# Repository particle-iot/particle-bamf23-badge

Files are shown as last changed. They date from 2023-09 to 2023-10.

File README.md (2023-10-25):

# Particle Bay Area Maker Faire 2023 Water Balloon Badge 

## Our interactive game

If you stopped by the Particle booth for the 2023 Bay Area Maker Faire, spun the prize wheel, and were lucky enough to win our badge, we hope you had a blast playing! 

So, how does it work? Participants turn on their badge(s) and wait for the small LED to glow cyan, letting them know it's ready for a game match to begin. The badge has four buttons, each serving as a launcher for virtual water balloons. Each button triggers attacks with varying strengths, all determined by a virtual die roll. Players take turns launching virtual water balloons, and after an attack and counter-attack, the badges will display the result of the match automatically.  The badge lights up green for a win, red for loss, or blue for a draw.  Players engage with fellow attendees in virtual water balloon battles, roll the dice, aim for high-strength attacks, and secure their win!

Players can only battle the same player up to 10 times (after which badges win glow white to alert you of the limit), so everyone must engage with new players to climb up the leaderboard.

Pro Tip: Point the die side edges of the badges towards each other for the best results (like the video below). The max distance is 10 feet, but the closer you are, the better.

Fun fact: iPhone IR depth mapping is detrimental to gameplay functionality.  So if you are wondering why your badges seem camera shy while videoing, this is why :D

## Gameplay

badge
cyberdeck

## Behind the Badge

The Photon 2 based badge isn't just a fun toy. With features like a dual-row socket for Photon 2, an ON/OFF switch, lanyard slots, 7 neopixel RGB LEDs, humidity and temperature sensor, QWIIC/Stemma connector, and a speaker, it's also a toolkit for your post-conference projects. The badge's 38kHz IR demodulator and LEDs also ensure efficient communication for the game.

## Hardware

All the parts are described in Bill of Materials [particle-bamf23-badge.csv](hardware/v1.0/pcb/)

OSHPark is a good place to order with purple or the new "after dark" theme color scheme.  You can upload the KiCad [particle-bamf23-badge.kicad_pcb](hardware/v1.0/pcb/) there directly.  I would download this entire Github repo ZIP file first though instead of just trying to save the PCB file from your browser.

Another way to order PCB's is by using the included [gerbers](hardware/v1.0/gerbers/) and uploading those with all of the necessary specs to companies like [PCBWay](https://www.pcbway.com) or [JLCPCB](https://jlcpcb.com)

The cyberdeck is a Raspberry Pi 400 computer, with Pimoroni Hyperpixel 4.0 Square LCD, along with another water balloon badge for input.  The badge is powered and connected to the pi over USB, and takes input on USB serial /dev/ttyACM0.  Everything was mounted to a laser cut acrylic piece that was bent at a nice angle.  The 40-pin cable was a real pain to make, since every pair of wires was twisted to ensure the proper orientation.  I highly suggest buying one of Adafruit's cyberdeck boards instead.

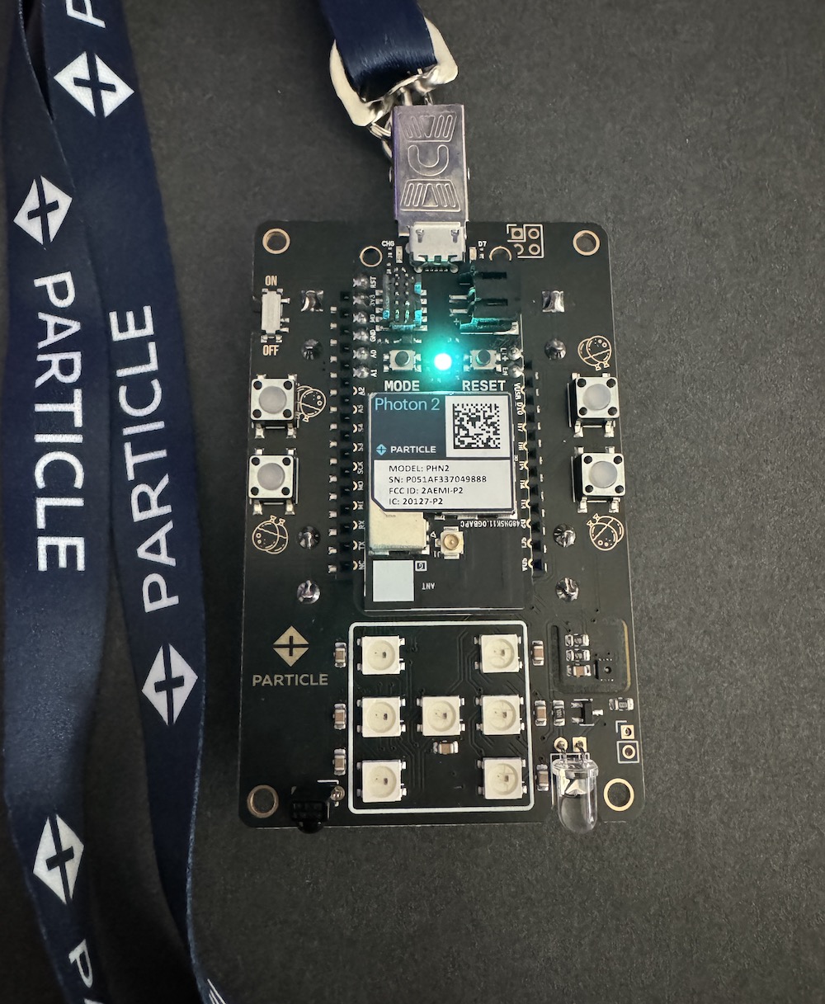
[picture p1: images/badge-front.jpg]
badge front

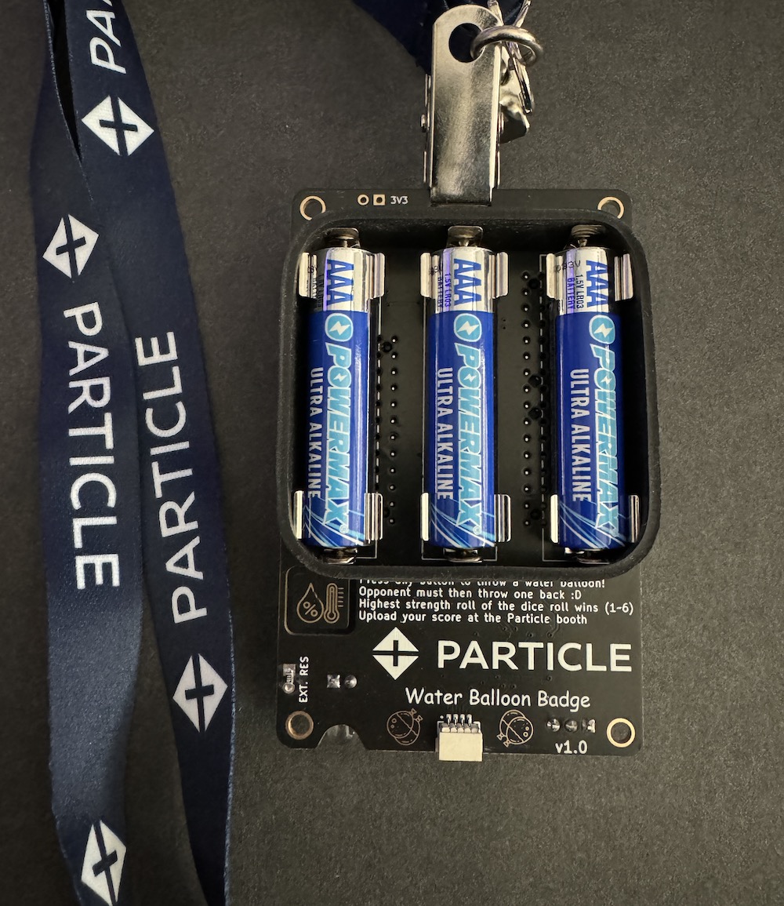
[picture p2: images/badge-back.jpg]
badge back

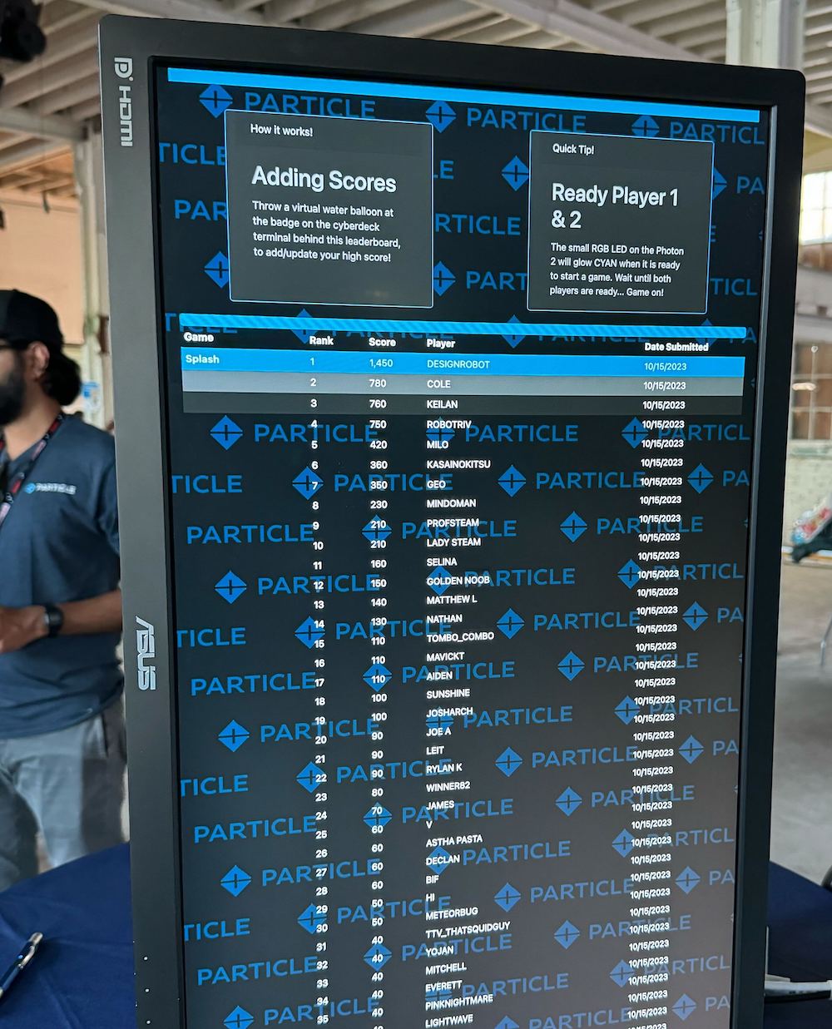
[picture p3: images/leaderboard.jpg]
badge


## Software

```
software/v1.0/badge (badge firmware)
software/v1.0/badge-build (badge build directory)
software/v1.0/badge-interface (badge-interface firmware)
software/v1.0/badge-interface-build (badge-interface build directory)
software/v1.0/leaderboard (cyberdeck software)
```

### Compile prerequisites

- Install [Particle CLI](https://docs.particle.io/getting-started/developer-tools/cli/)
- Login to the CLI with your Particle account `particle login`
- Install [Device OS Flash Util](https://github.com/particle-iot/device-os-flash-util)

### Badge

To build the badge firmware, connect a badge over USB and run:

```
cd software/v1.0/badge-build
./build.sh 5.5.0
```

### On-Board SHT31 Temperature/Humidity

To build the SHT31 Temperature/Humidity Demo:

```
change the #define ENABLE_ON_BOARD_SHT31 to (1) at the top of the particle-bamf23-badge.cpp file
cd software/v1.0/badge-build
./build.sh 5.5.0
```

### QWIIC/STEMMA Conenctor Support

To build the QWIIC/STEMMA Conenctor Demo:
I used the VCNL4040 Ambient Light Sensor, but there are tons of sensors to experiment with

```
change the #define ENABLE_QWIIC_SENSOR_DEMO to (1) at the top of the particle-bamf23-badge.cpp file
cd software/v1.0/badge-build
./build.sh 5.5.0
```

### Badge Interface (for Cyberdeck)

To build the badge-interface firmware, connect a badge over USB and run:

```
cd software/v1.0/badge-interface-build
./build.sh 5.5.0
```

### Cyberdeck

To run the cyberdeck software on a Raspberry Pi-400:

```
- copy the cyberdeck folder to your raspberry pi
- ensure node.js is installed ( https://pimylifeup.com/raspberry-pi-nodejs (other seemingly simpler ways didn't work!) )
- ensure electron is installed globally `npm i -g electron`
- run `npm install` the first time to populate all of the libraries
- in one terminal tab run `electron electron.js`
- in another terminal tab run `node server.js`
- Note: this will likely crash without the leaderboard server running as well, accepting score requests.  I'm leaving that part as an excercise for you.  You can use an express app to accomplish this, with some effort :D  Your leaderboard server should use a local MongoDB so you can restart it from time to time without losing the scores and user nicknames collected.  I ended up implementing separate collections for users and game/score data.
```

# License

Creative Commons Attribution-ShareAlike 4.0 International (CC BY-SA 4.0) - essentially do whatever you want, Full [LICENSE here](LICENSE)

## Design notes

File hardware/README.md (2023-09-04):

# Particle BAMF23 Badge "Water Balloon Badge" PCB

Details!!!

# CREDITS

- Badge inspired by [Roshamglo badge from Sparkfun](https://www.sparkfun.com/products/retired/14130).
- [Temp/Humidity](https://www.flaticon.com/free-icons/humidity) and [Water Balloon](https://www.flaticon.com/free-icons/water-balloons) icons from flaticon.com

# LICENSE

Creative Commons Attribution-ShareAlike 4.0 International (CC BY-SA 4.0) - essentially do whatever you want, Full [LICENSE here](../../LICENSE)

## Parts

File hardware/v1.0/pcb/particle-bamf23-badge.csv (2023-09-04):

Date: | 2023 August 28, Monday 18:32:26
Tool: | Eeschema 7.0.7
Generator: | /Applications/KiCad/KiCad.app/Contents/SharedSupport/plugins/bom_csv_grouped_by_value_with_fp.py
Component Count: | 55
Ref | Qnty | Value | Cmp name | Footprint | Description | Vendor Part # | Vendor | DNP | Comment
BT1, BT2, BT3 | 6 | AAA Battery Holder | Battery | particle-bamf23-badge:BatteryHolder_MPD_BK82_AAA | Multiple-cell battery | BK-82 | Memory Protection Devices |  | I combined 2 pieces into 1 footprint, so qty. is really 6.
C1, C2, C3, C4, C5, C6, C7, C8, C9 | 9 | 0.1uF | C_Small | particle-bamf23-badge:C_0805_2012Metric_Pad1.20x1.40mm_HandSolder | Unpolarized capacitor, small symbol | 0805 X7R CER CAP
D1 | 1 | SBA330AH_R1_00001 | Diode | particle-bamf23-badge:D_SOD-123HE | Diode 30 V 3A Surface Mount SOD-123HE | SBA330AH_R1_00001 | Panjit International Inc. |  | Used on Photon 2
D2 | 1 | IR LED | LED | particle-bamf23-badge:LED_Harvatek_B4301IR | Light emitting diode | B4301IR | Harvatek | X
D3, D4, D5, D6, D7, D8, D9 | 7 | WS2812B | WS2812B | particle-bamf23-badge:LED_WS2812B_PLCC4_5.0x5.0mm_P3.2mm | RGB LED with integrated controller | WS2812B |  |  | 4 pin version, not 6 pin version
D10 | 1 | MBR0540 | MBR0540 | particle-bamf23-badge:D_SOD-123 | 40V 0.5A Schottky Power Rectifier Diode, SOD-123 | MBR0540 | Diodes Inc.
D11 | 1 | IR LED | LED | particle-bamf23-badge:LED_D5.0mm_Horizontal_O1.27mm_Z3.0mm | Light emitting diode | OED-EL-1L2 | Lumex Opto/Components Inc.
J2, J5 | 2 | M20-7810845 | Conn_01x08 | particle-bamf23-badge:Harwin_M20-7810845_2x08_P2.54mm_Vertical | Generic connector, single row, 01x08, script generated (kicad-library-utils/schlib/autogen/connector/) | M20-7810845 | Harwin |  | 2x the 8x2 version, or if we can find 1x 16x2 version. Harwin doesn't make one.
J3 | 1 | Qwiic_RA | Qwiic_Right_Angle | particle-bamf23-badge:JST04_1MM_RA | 4 pin JST 1mm polarized connector for I2C | SM04B-SRSS-TB | JST |  | Color black if possible
J4 | 1 | M20-7811245 | Conn_01x12 | particle-bamf23-badge:Harwin_M20-7811245_2x12_P2.54mm_Vertical | Generic connector, single row, 01x12, script generated (kicad-library-utils/schlib/autogen/connector/) | M20-7811245 | Harwin
J6 | 1 | PinHeader_2x02_P2.54mm_Vertical | Conn_02x02 | particle-bamf23-badge:PinHeader_2x02_P2.54mm_Vertical | Generic connector, dual row, 02x02, Female |  |  | X
LS1 | 1 | Speaker | Speaker | particle-bamf23-badge:MagneticBuzzer_FUET-9032-05 | Speaker | FUET-9032-05
Q1, Q2, Q4 | 3 | 2N7002 | 2N7002 | particle-bamf23-badge:SOT-23_HandSoldering | 0.115A Id, 60V Vds, N-Channel MOSFET, SOT-23 | 2N7002 |  |  | Or evivelent
Q3 | 1 | PJA3415 | Q_PMOS_GSD | particle-bamf23-badge:SOT-23_HandSoldering | P-MOSFET transistor, gate/source/drain | PJA3415 |  |  | Used on Photon 2
R1, R3, R5, R8 | 4 | 100k 1% | R | particle-bamf23-badge:R_0805_2012Metric_Pad1.20x1.40mm_HandSolder | Resistor | 0805 100k 1%
R2 | 1 | 1k 1% | R | particle-bamf23-badge:R_0805_2012Metric_Pad1.20x1.40mm_HandSolder | Resistor | 0805 1k 1%
R4 | 1 | 10k 1% | R | particle-bamf23-badge:R_0805_2012Metric_Pad1.20x1.40mm_HandSolder | Resistor | 0805 10k 1%
R6, R7 | 2 | 4.7k 1% | R | particle-bamf23-badge:R_0805_2012Metric_Pad1.20x1.40mm_HandSolder | Resistor | 0805 4.7k 1%
SW1, SW2, SW3, SW4 | 4 | 6x6x5mm | SW_Push | particle-bamf23-badge:SW_Push_1P1T_NO_6x6mm_H5mm | Push button switch, generic, two pins | A04-11-F02_6*6*5 |  |  | 130g force if possible, these are the silicone one we ordered before, Eric.
SW5 | 1 | SW_SPDT | SW_SPDT | particle-bamf23-badge:SW_SPDT_PCM12 | Switch, single pole double throw | PCM12SMTR | C&K
U1 | 1 | 74AHC1G125 | 74AHC1G125 | particle-bamf23-badge:SOT-23-5_HandSoldering | Single Buffer Gate Tri-State, Low-Voltage CMOS | 74AHC1G125
U2 | 1 | TSOP38G36 | TSOP38238 | OptoDevice:Vishay_MINICAST-3Pin | Photo Modules for PCM Remote Control Systems | TSOP38238
U3 | 1 | SHT31-DIS | SHT31-DIS | particle-bamf23-badge:Sensirion_DFN-8-1EP_2.5x2.5mm_P0.5mm_EP1.1x1.7mm | I²C humidity and temperature sensor, ±2%RH, ±0.2°C, DFN-8 | SHT31-DIS |  |  | SHT31-DIS or SHT31A-DIS (whatever we have in stock)

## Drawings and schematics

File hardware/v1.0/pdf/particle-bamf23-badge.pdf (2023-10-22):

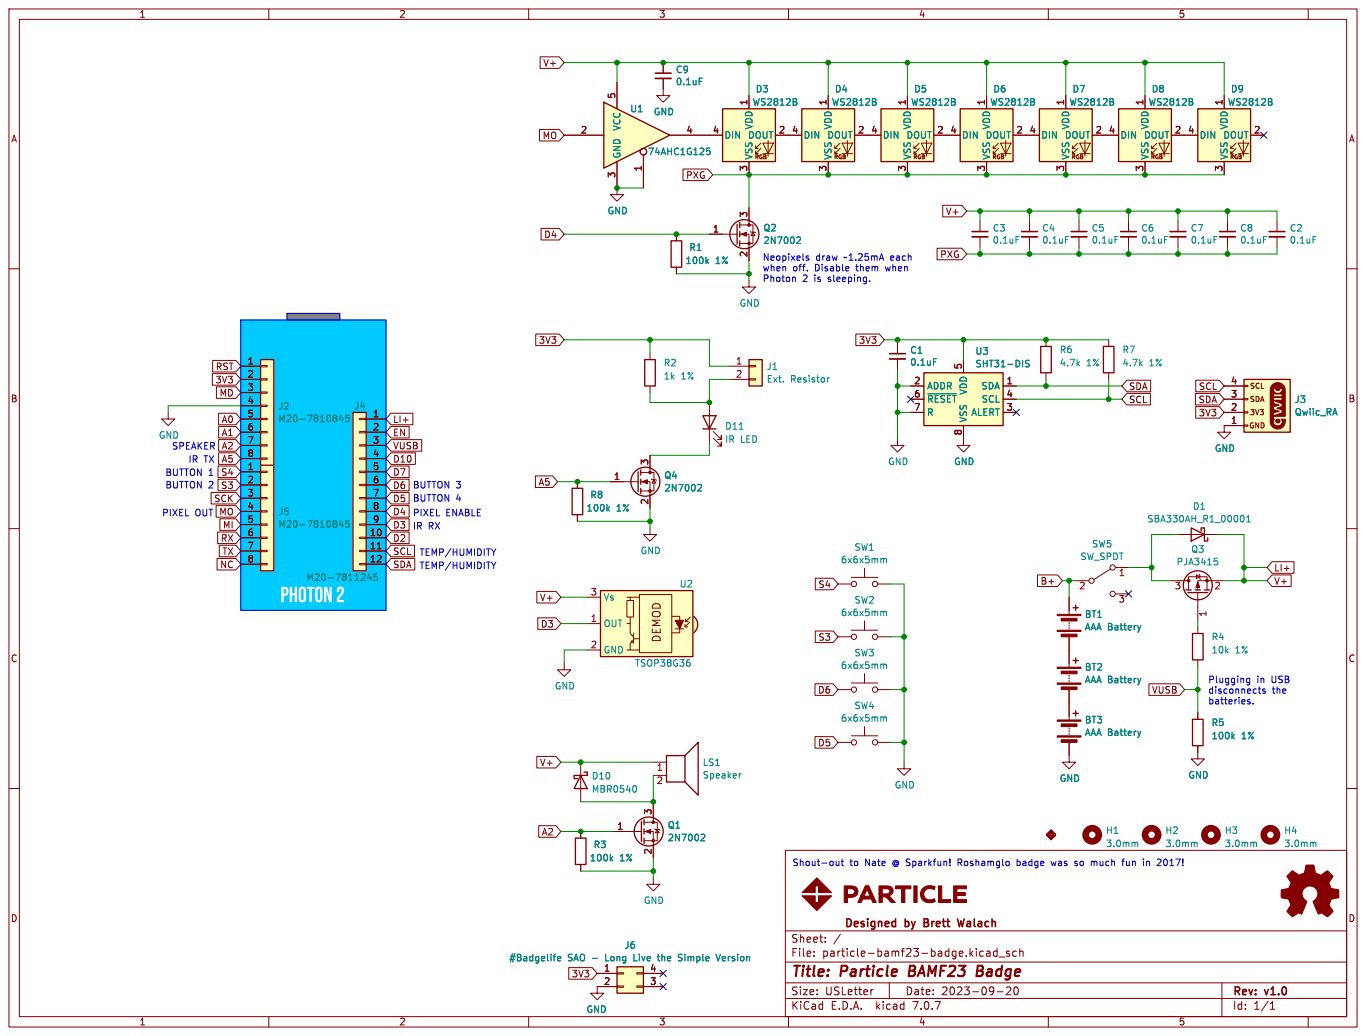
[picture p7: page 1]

3 DIN 4 BT1 AAA Battery BT2 AAA Battery BT3 AAA Battery GND GND

8 U3SHT31-DIS GND GND GND

BT2 AAA Battery BT1 AAA Battery SW2

Id: 1/1 Title: Particle BAMF23 Badge

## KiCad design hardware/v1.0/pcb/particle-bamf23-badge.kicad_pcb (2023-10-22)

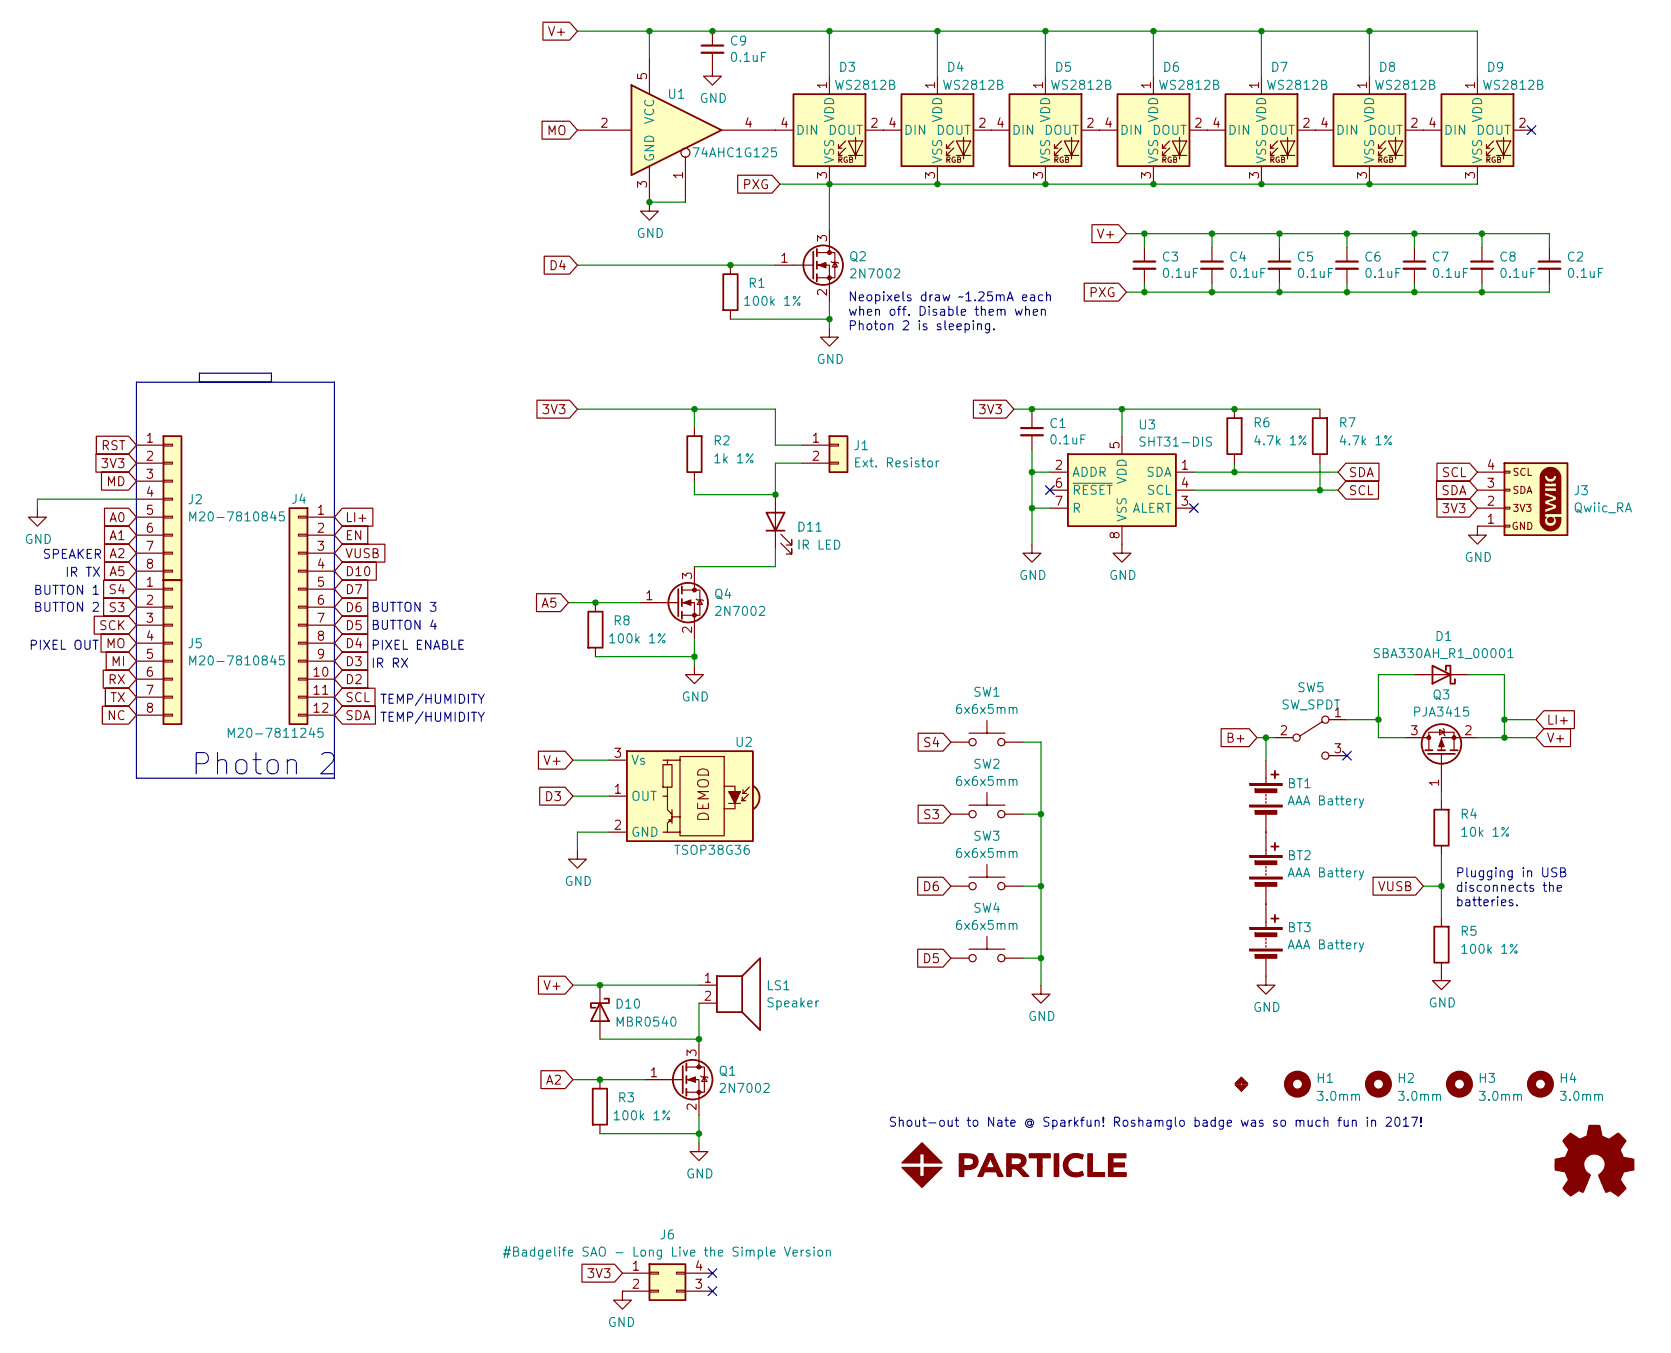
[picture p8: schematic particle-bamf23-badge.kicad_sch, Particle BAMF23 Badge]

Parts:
BT1, BT2, BT3: AAA Battery; BatteryHolder_MPD_BK82_AAA
C1, C2, C3, C4, C5, C6, C7, C8, C9: 0.1uF; C_0805_2012Metric_Pad1.20x1.40mm_HandSolder
D1: SBA330AH_R1_00001; D_SOD-123HE
D3, D4, D5, D6, D7, D8, D9: WS2812B; LED_WS2812B_PLCC4_5.0x5.0mm_P3.2mm
D10: MBR0540; D_SOD-123
D11: IR LED; LED_D5.0mm_Horizontal_O1.27mm_Z3.0mm
G1: LOGO; particle-logo-stacked-10mm-sm
G2: LOGO; particle-logo-38mm-ss
H1, H2, H3, H4: 3.0mm; MountingHole_4.0mm_M3.0
J1: Ext. Resistor; PinHeader_1x02_P2.54mm_Vertical
J2, J5: M20-7810845; Harwin_M20-7810845_2x08_P2.54mm_Vertical
J3: Qwiic_RA; JST04_1MM_RA
J4: M20-7811245; Harwin_M20-7811245_2x12_P2.54mm_Vertical
J6: #Badgelife SAO - Long Live the Simple Version; PinHeader_2x02_P2.54mm_Vertical
LS1: Speaker; MagneticBuzzer_FUET-9032-05
Q1, Q2, Q4: 2N7002; SOT-23_HandSoldering
Q3: PJA3415; SOT-23_HandSoldering
R1, R3, R5, R8: 100k 1%; R_0805_2012Metric_Pad1.20x1.40mm_HandSolder
R2: 1k 1%; R_0805_2012Metric_Pad1.20x1.40mm_HandSolder
R4: 10k 1%; R_0805_2012Metric_Pad1.20x1.40mm_HandSolder
R6, R7: 4.7k 1%; R_0805_2012Metric_Pad1.20x1.40mm_HandSolder
SW1, SW2, SW3, SW4: 6x6x5mm; SW_Push_1P1T_NO_6x6mm_H5mm
SW5: SW_SPDT; SW_SPDT_PCM12
U1: 74AHC1G125; SOT-23-5_HandSoldering
U2: TSOP38G36; Vishay_MINICAST-3Pin
U3: SHT31-DIS; Sensirion_DFN-8-1EP_2.5x2.5mm_P0.5mm_EP1.1x1.7mm

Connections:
3V3: C1.1, J1.1, J2.2, J3.2, J6.1, R2.2, R6.2, R7.2, U3.5 (VDD)
A0: J2.5
A1: J2.6
A2: J2.7, Q1.1 (G), R3.1
A5: J2.8, Q4.1 (G), R8.1
B+: BT1.1 (+), SW5.2 (B)
D2: J4.10
D3: J4.9, U2.1 (OUT)
D4: J4.8, Q2.1 (G), R1.1
D5: J4.7, SW4.1
D6: J4.6, SW3.1
D7: J4.5
D10: J4.4
EN: J4.2
GND: BT3.2 (-), C1.2, C9.2, J2.4, J3.1, J6.2, Q1.2 (S), Q2.2 (S), Q4.2 (S), R1.2, R3.2, R5.1, R8.2, SW1.2, SW2.2, SW3.2, SW4.2, U1.1, U1.3 (GND), U2.2 (GND), U3.2 (ADDR), U3.7 (R), U3.8 (VSS), U3.9 (VSS)
LI+: C2.1, C3.1, C4.1, C5.1, C6.1, C7.1, C8.1, C9.1, D1.1 (K), D3.1 (VDD), D4.1 (VDD), D5.1 (VDD), D6.1 (VDD), D7.1 (VDD), D8.1 (VDD), D9.1 (VDD), D10.1 (K), J4.1, LS1.1, Q3.2 (S), U1.5 (VCC), U2.3 (Vs)
MD: J2.3
MI: J5.5
MO: J5.4, U1.2
NC: J5.8
unnamed: BT1.2 (-), BT2.1 (+)
unnamed: BT2.2 (-), BT3.1 (+)
unnamed: D1.2 (A), Q3.3 (D), SW5.1 (A)
unnamed: D3.4 (DIN), U1.4
unnamed: D3.2 (DOUT), D4.4 (DIN)
unnamed: D4.2 (DOUT), D5.4 (DIN)
unnamed: D5.2 (DOUT), D6.4 (DIN)
unnamed: D6.2 (DOUT), D7.4 (DIN)
unnamed: D7.2 (DOUT), D8.4 (DIN)
unnamed: D8.2 (DOUT), D9.4 (DIN)
unnamed: D10.2 (A), LS1.2, Q1.3 (D)
unnamed: D11.2 (A), J1.2, R2.1
unnamed: D11.1 (K), Q4.3 (D)
unnamed: Q3.1 (G), R4.2
PXG: C2.2, C3.2, C4.2, C5.2, C6.2, C7.2, C8.2, D3.3 (VSS), D4.3 (VSS), D5.3 (VSS), D6.3 (VSS), D7.3 (VSS), D8.3 (VSS), D9.3 (VSS), Q2.3 (D)
RST: J2.1
RX: J5.6
S3: J5.2, SW2.1
S4: J5.1, SW1.1
SCK: J5.3
SCL: J3.4, J4.11, R7.1, U3.4 (SCL)
SDA: J3.3, J4.12, R6.1, U3.1 (SDA)
TX: J5.7
VUSB: J4.3, R4.1, R5.2

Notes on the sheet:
Shout-out to Nate @ Sparkfun! Roshamglo badge was so much fun in 2017!
BUTTON 3
BUTTON 4
PIXEL OUT
BUTTON 2
IR TX
Plugging in USB disconnects the batteries.
IR RX
Photon 2
PIXEL ENABLE
Neopixels draw ~1.25mA each when off. Disable them when Photon 2 is sleeping.
SPEAKER
TEMP/HUMIDITY
BUTTON 1

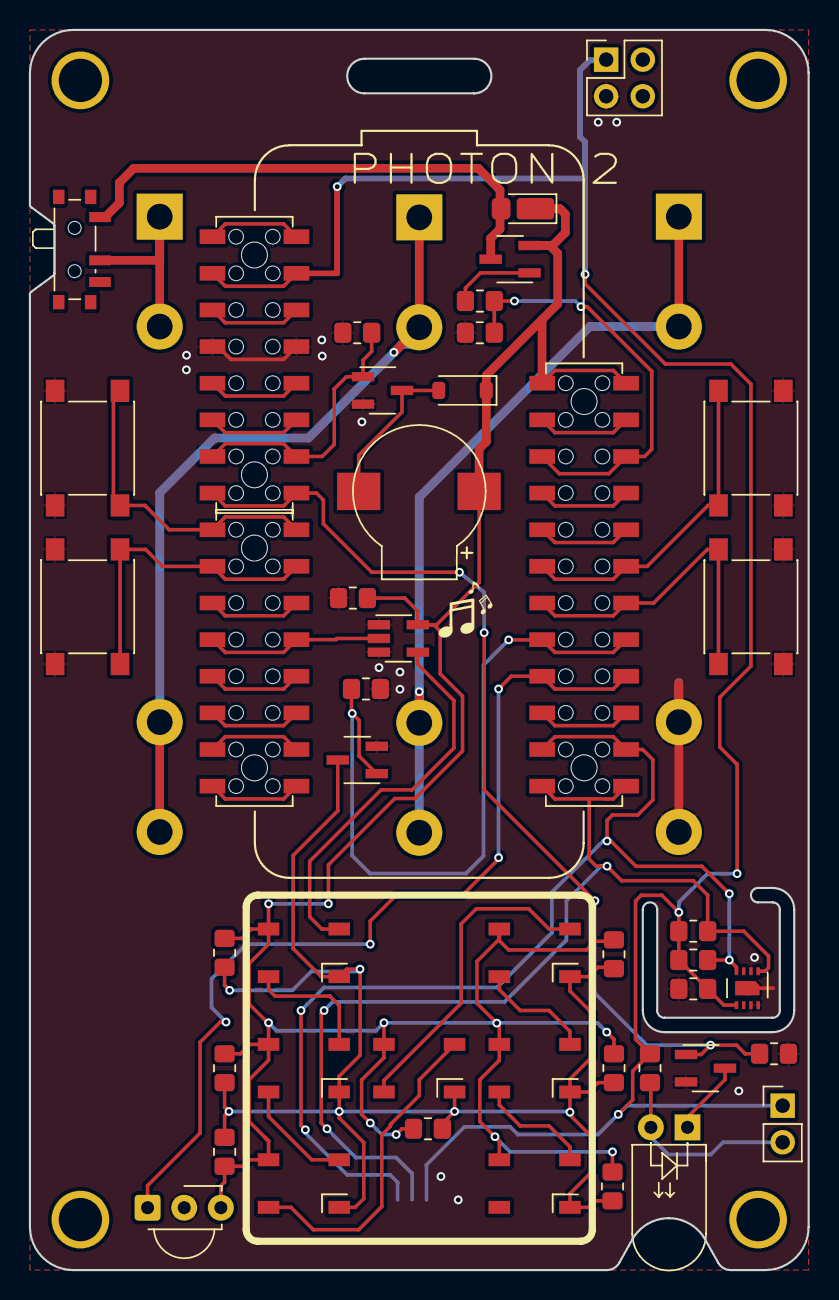
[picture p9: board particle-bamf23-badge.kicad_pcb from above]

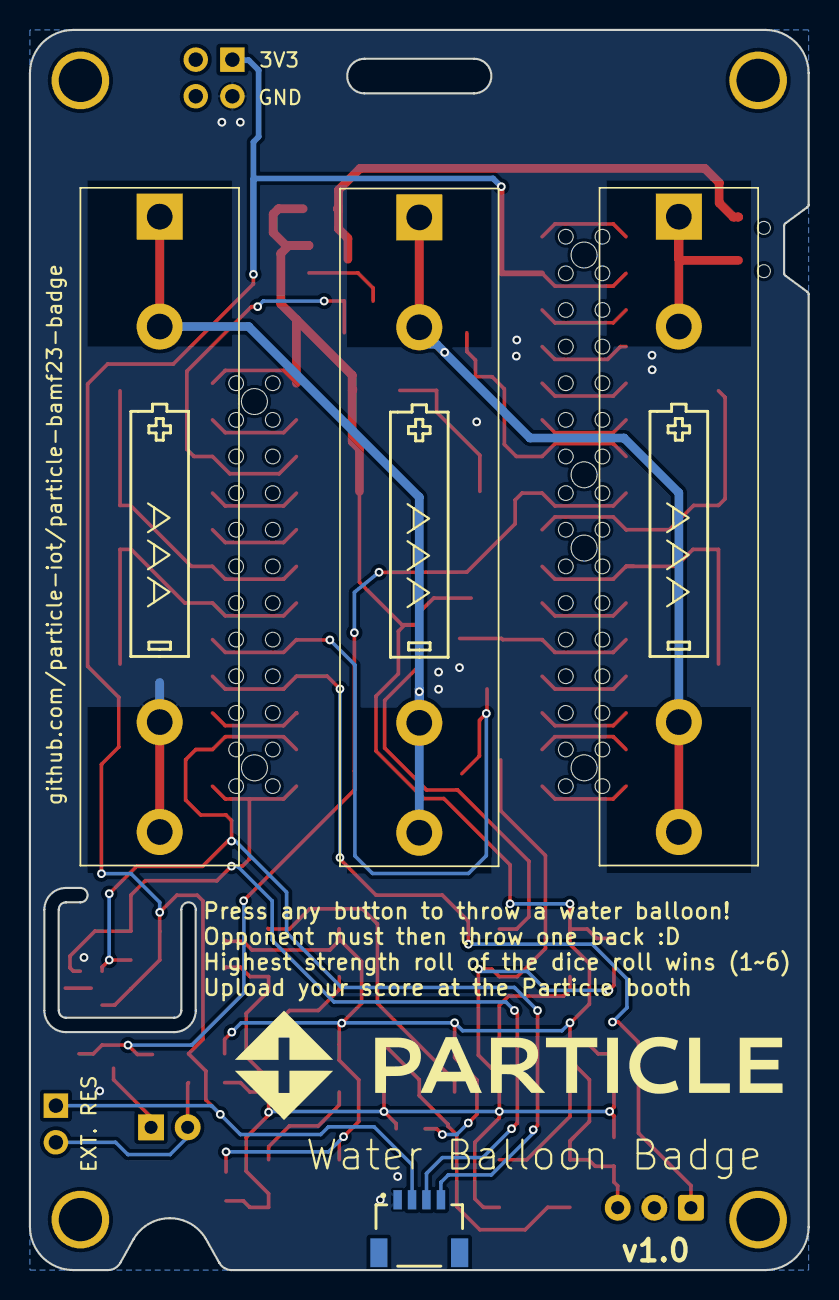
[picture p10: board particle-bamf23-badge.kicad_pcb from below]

Board: 2 copper layers, 54.0 x 86.0 mm, 55 parts (5 on the bottom side), 31 nets.

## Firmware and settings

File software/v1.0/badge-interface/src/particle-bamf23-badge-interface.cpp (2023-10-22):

/*
 * Particle Bay Area Maker Faire 2023 Badge Interface
 *
 * Based on the badge code, this code only receives
 * scores for the cyberdeck, and outputs the id:score data over USB serial.
 * If any button is held on the cyberdeck badge when the score is received, the name will be edited.
 *
 * by Brett Walach ( @Technobly / github.com/technobly )
 * July 30th, 2023
 *
 */

#include "Particle.h"
#include "IRremoteLearn.h"
#include "neopixel.h"

SYSTEM_MODE(SEMI_AUTOMATIC);
SYSTEM_THREAD(ENABLED);

// MOSI pin MO
#define PIXEL_PIN SPI
#define PIXEL_COUNT 7
#define PIXEL_TYPE WS2812B

const int BUTTON_1_PIN = S4;
const int BUTTON_2_PIN = S3;
const int BUTTON_3_PIN = D6;
const int BUTTON_4_PIN = D5;
const int PIXEL_ENABLE_PIN = D4;
const int SPEAKER_PIN = A2;
const int IR_TX_PIN = A5;
const int IR_RX_PIN = D3;

Adafruit_NeoPixel strip(PIXEL_COUNT, PIXEL_PIN, PIXEL_TYPE);

// ATTACK (P1): HEADER:P1_ID:[MSG_TYP:MSG_BTN:MSG_STR]:P1_SCORE:CRC
//              1:4:1:2 (8)
//
// COUNTER(P2): HEADER:P2_ID:[MSG_TYP:MSG_BTN:MSG_STR]:P2_SCORE:P1_ID:[MSG_TYP:MSG_BTN:MSG_STR]:CRC
//              1:4:1:2:4:1 (13)
//
// RESULT (P1): HEADER:P1_ID:[MSG_TYP:MSG_BTN:MSG_STR]:P1_P2_ID:CRC
//              1:4:1:4 (10)
//
// SCORE_ACK(P2): HEADER:P1_ID:[MSG_TYP:MSG_BTN:MSG_STR]:P1_SCORE:CRC
//                1:4:1:2 (8)
//
#define MAGIC_HEADER_BYTE                   (0xA2)
#define MESSAGE_TYPE_MASK                   (0xE0)
#define MESSAGE_BUTTON_MASK                 (0x18)
#define MESSAGE_STRENGTH_MASK               (0x07)
#define MESSAGE_TYPE_OFFSET                 (5)
#define MESSAGE_BUTTON_OFFSET               (3)
#define MESSAGE_STRENGTH_OFFSET             (0)

#define MESSAGE_TYPE_ATTACK                 (0)
#define MESSAGE_TYPE_ATTACK_ACK             (1)
#define MESSAGE_TYPE_COUNTER_ATTACK         (2)
#define MESSAGE_TYPE_COUNTER_ATTACK_ACK     (3)
#define MESSAGE_TYPE_RESULT                 (4)
#define MESSAGE_TYPE_RESULT_ACK             (5)
#define MESSAGE_TYPE_SCORE_ACK              (6)

#define MESSAGE_TYPE_ATTACK_LEN             (8)
#define MESSAGE_TYPE_ATTACK_ACK_LEN         (8)
#define MESSAGE_TYPE_COUNTER_ATTACK_LEN     (13)
#define MESSAGE_TYPE_COUNTER_ATTACK_ACK_LEN (13)
#define MESSAGE_TYPE_RESULT_LEN             (10)
#define MESSAGE_TYPE_RESULT_ACK_LEN         (10)
#define MESSAGE_TYPE_SCORE_ACK_LEN          (8)

#define SOUND_STATE_IDLE                    (0)
#define SOUND_STATE_NEW                     (1)
#define SOUND_STATE_PLAYING                 (2)
#define SOUND_STATE_FINISHED                (3)

#define DIE_ROLL_INTERVAL_MS                (50)
#define DIE_ROLL_TIMEOUT_MS                 (1000)
#define DIE_ROLL_TIMEOUT_MAX_MS             (2000)
#define DIE_ROLL_STATE_IDLE                 (0)
#define DIE_ROLL_STATE_NEW                  (1)
#define DIE_ROLL_STATE_THROW                (2)
#define DIE_ROLL_STATE_ROLLING              (3)
#define DIE_ROLL_STATE_FINISHED             (4)

#define DIE_COLOR_MAGENTA                   (1)
#define DIE_COLOR_CYAN                      (2)
#define DIE_COLOR_YELLOW                    (3)
#define DIE_COLOR_BLUE                      (4)
#define DIE_COLOR_RED                       (5)
#define DIE_COLOR_GREEN                     (6)
#define DIE_COLOR_WHITE                     (7)

#define GAME_RESULT_WIN                     (0)
#define GAME_RESULT_LOSE                    (1)
#define GAME_RESULT_DRAW                    (2)
#define GAME_RESULT_INVALID                 (3)

#define BADGE_STATE_IDLE                    (0)
#define BADGE_STATE_WAKEUP                  (1)
#define BADGE_STATE_SLEEP                   (2)
#define BADGE_STATE_MESSAGE_AVAILABLE       (3)
#define BADGE_STATE_DIE_ROLL_INIT           (4)
#define BADGE_STATE_DIE_ROLL                (5)
#define BADGE_STATE_SPLASH                  (6)
#define BADGE_STATE_DISPLAY_RESULT          (7)
int badgeState = BADGE_STATE_IDLE;

#define GAMEPLAY_STATE_IDLE                 (0)
#define GAMEPLAY_STATE_ATTACK               (1)
#define GAMEPLAY_STATE_ATTACK_ACK           (2)
#define GAMEPLAY_STATE_COUNTER_ATTACK       (3)
#define GAMEPLAY_STATE_COUNTER_ATTACK_ACK   (4)
#define GAMEPLAY_STATE_RESULT               (5)
#define GAMEPLAY_STATE_RESULT_ACK           (6)
#define GAMEPLAY_STATE_SCORE_ACK            (7)
#define GAMEPLAY_STATE_RESULT_DISPLAY       (8)
int gameStateP1 = GAMEPLAY_STATE_IDLE; // our state machine
int gameStateP2 = GAMEPLAY_STATE_IDLE; // keep track of their state machine

struct IRMessage {
                                   // MSB[AAA:BB:CCC]LSB
    uint8_t strength:3;            //      |  |  \----- C = Strength (0-6)
    uint8_t button:2;              //      |  \-------- B = Button   (0-3)
    uint8_t type:3;                //      \----------- A = Type     (0-6)
};
struct IRData {
    uint8_t header;                // 0xA2 magic header byte, ó <- looks like a little water ballon
    uint32_t id;                   // Self ID
    IRMessage msg;                 // Message [x:Type:Button:Strength]
    uint16_t score;                // Score always transmitted, used by leaderboard
    uint32_t id2;                  // Other ID
    IRMessage msg2;                // Message2 [x:Type:Button:Strength]
    uint8_t valid;                 // Data valid
};
IRData irDataTx;
IRData irDataRx;
IRData irDataRxCurrent; // saved copy of Rx message to compare through the state machine

decode_results irResults;
system_tick_t lastSleep = 0;
int wakeupReason = 0;
int wakeupPin = PIN_INVALID;
int colorPick = 0;
bool muteSound = false;
int renamePlayer = 0;

uint16_t player1score = 0;
uint16_t player2score = 0;

uint32_t player2id = 0;
IRMessage player1msg = {};
IRMessage player2msg = {};

uint32_t winner_id = 0;
uint32_t received_winner_id = 0;
#define GAME_IS_A_DRAW_ID (0x13371337)
int gameResult = GAME_RESULT_INVALID;

uint8_t randomNumber = 1;
uint32_t startDieRoll = 0;
uint32_t startGamestateTimer = 0;
int rolling = 0;
int retransmits = 0;
uint32_t startRetransmit = 0;
uint32_t retransmitDelay = 500;
#define GAME_STATE_TIMEOUT_MS (5000)
#define DATA_BUF_LEN (13) // HEADER,                P1_ID, [MSG_TYP, MSG_BTN, MSG_STR], P1_SCORE, CRC
uint8_t dataBuf[DATA_BUF_LEN] = {}; // {0xA2,   0x12,0x34,0x56,0x78,                  0b00110111,     1200, 9};

void rainbow(uint8_t wait);
uint32_t colorWheel(byte colorWheelPos);
void fadeOut(uint16_t wait);
int parse(decode_results *results);
int buttonPressed();
void extendWakeTime();
void sleepAfterDelay();
int playSound(uint8_t sound, int soundState);
void setDieNum(uint8_t num, uint32_t color);
int dieRoll(uint8_t finalRandomNumber, uint32_t color, bool newRoll = false);
void createMessage(uint8_t* buf, int msgType, int button, int strength, uint32_t player2id = 0, void* player2msg = nullptr);

const unsigned long SLEEP_TIMEOUT_MS = 60000;

// Default 300ms idle timeout, 200us mark timeout
// IRrecv irrecv(IR_RX_PIN);

// Optionally specify your own timeouts
const unsigned long IDLE_TIMEOUT_MS = 100;
const unsigned long MARK_TIMEOUT_US = 200;
IRrecv irrecv(IR_RX_PIN, IDLE_TIMEOUT_MS, MARK_TIMEOUT_US);

IRsend irsend(IR_TX_PIN);

extern uint8_t crc8(uint8_t data[], uint8_t len);

STARTUP(
    pinMode(D7, INPUT_PULLDOWN);
    irrecv.enableIRIn(); // Start the receiver
)

uint32_t deviceID_last4() {
    String idStr = System.deviceID();
    String idShort = idStr.substring(idStr.length()-8, idStr.length());
    // Serial.printlnf("%s %s", idStr.c_str(), idShort.c_str());
    char *ptr;
    return strtoul(idShort.c_str(), &ptr, 16);
}

bool ids_equal(uint32_t my_id, uint32_t rcv_id) {
    return (my_id == rcv_id);
}

// #define PAR_LEN_OFF    (0)
// #define PAR_HDR_OFF    (1)
// #define PAR_ID1_OFF    (2)
//                      //(3)
//                      //(4)
//                      //(5)
// #define PAR_MSG1_OFF   (6)
// #define PAR_WIN_ID_OFF (7)
// #define PAR_SCR1_OFF   (7)
// #define PAR_SCR2_OFF   (8)
// #define PAR_ID2_OFF    (9)
//                      //(10)
//                      //(11)
//                      //(12)
// #define PAR_MSG2_OFF   (13)
// #define PAR_CRC_OFF    (14)

#define PAR_LEN_OFF    (0)
// #define PAR_HDR_OFF    (1)
#define PAR_ID1_OFF    (1)
                     //(2)
                     //(3)
                     //(4)
#define PAR_MSG1_OFF   (5)
#define PAR_WIN_ID_OFF (6)
#define PAR_SCR1_OFF   (6)
#define PAR_SCR2_OFF   (7)
#define PAR_ID2_OFF    (8)
                     //(9)
                     //(10)
                     //(11)
#define PAR_MSG2_OFF   (12)
#define PAR_CRC_OFF    (13)
int parse(decode_results *results) {
    // Parses the decode_results structure.
    // Call this after IRrecv::decode()

    // Serial.print("Decoded BYTES: ");
    // for (int i = 0; i < results->rx_len; i++) {
    //     Serial.printf("%02X ", results->rx_data[i]);
    // }

    memset(&irDataRx, 0, sizeof(irDataRx));
    irDataRx.valid = 0;

    // irDataRx.header = results->rx_data[MSG_HDR_OFF];
    // if (irDataRx.header != MAGIC_HEADER_BYTE) {
    //     return -1;
    // }

    uint8_t type = (results->rx_data[PAR_MSG1_OFF] & MESSAGE_TYPE_MASK) >> MESSAGE_TYPE_OFFSET;
    if (type != MESSAGE_TYPE_COUNTER_ATTACK && type != MESSAGE_TYPE_COUNTER_ATTACK_ACK) {
        irDataRx.msg.type = (results->rx_data[PAR_MSG1_OFF] & MESSAGE_TYPE_MASK) >> MESSAGE_TYPE_OFFSET;
        irDataRx.msg.button = (results->rx_data[PAR_MSG1_OFF] & MESSAGE_BUTTON_MASK) >> MESSAGE_BUTTON_OFFSET;
        irDataRx.msg.strength = (results->rx_data[PAR_MSG1_OFF] & MESSAGE_STRENGTH_MASK) >> MESSAGE_STRENGTH_OFFSET;
        // Serial.printf(" T1:%d B1:%d S1:%d ", irDataRx.msg.type, irDataRx.msg.button, irDataRx.msg.strength);
    } else {
        irDataRx.msg.type = (results->rx_data[PAR_MSG1_OFF] & MESSAGE_TYPE_MASK) >> MESSAGE_TYPE_OFFSET;
        irDataRx.msg.button = (results->rx_data[PAR_MSG1_OFF] & MESSAGE_BUTTON_MASK) >> MESSAGE_BUTTON_OFFSET;
        irDataRx.msg.strength = (results->rx_data[PAR_MSG1_OFF] & MESSAGE_STRENGTH_MASK) >> MESSAGE_STRENGTH_OFFSET;
        irDataRx.msg2.type = (results->rx_data[PAR_MSG2_OFF] & MESSAGE_TYPE_MASK) >> MESSAGE_TYPE_OFFSET;
        irDataRx.msg2.button = (results->rx_data[PAR_MSG2_OFF] & MESSAGE_BUTTON_MASK) >> MESSAGE_BUTTON_OFFSET;
        irDataRx.msg2.strength = (results->rx_data[PAR_MSG2_OFF] & MESSAGE_STRENGTH_MASK) >> MESSAGE_STRENGTH_OFFSET;
        // Serial.printf(" T1:%d B1:%d S1:%d T2:%d B2:%d S2:%d ", irDataRx.msg.type, irDataRx.msg.button, irDataRx.msg.strength,
                                                              // irDataRx.msg2.type, irDataRx.msg2.button, irDataRx.msg2.strength);
    }

    player2score = (results->rx_data[PAR_SCR1_OFF] << 8) + results->rx_data[PAR_SCR2_OFF];
    // Serial.printf("player2score:%d", player2score);

    uint32_t rcv_id = 0;
    uint32_t win_id = 0;
    uint32_t acked_id = 0;
    memcpy(&rcv_id, &results->rx_data[PAR_ID1_OFF], 4);
    if (ids_equal(deviceID_last4(), rcv_id)) {
        // Serial.println("My own ID!!");
        return -2;
    } else {
        // Serial.println("Another ID!!");
    }
    irDataRx.id = rcv_id;

    if (irDataRx.msg.type == MESSAGE_TYPE_RESULT || irDataRx.msg.type == MESSAGE_TYPE_RESULT_ACK) {
        memcpy(&win_id, &results->rx_data[PAR_WIN_ID_OFF], 4);
        // Serial.printlnf("(US) player1id:%08lX %d [win_id:%08lX] player2id:%08lX %d (THEM)", deviceID_last4(), player1msg.strength, win_id, player2id, player2msg.strength);
        if (ids_equal(deviceID_last4(), win_id) ||
                ids_equal(player2id, win_id) ||
                ids_equal(GAME_IS_A_DRAW_ID, win_id)) {
            irDataRx.id2 = win_id;
            received_winner_id = win_id;
        } else {
            // Serial.println("Unknown winner ID!!");
            irDataRx.id2 = 0;
            received_winner_id = 0xdeadbeef;
            return -3;
        }
    } else if (irDataRx.msg.type == MESSAGE_TYPE_COUNTER_ATTACK) {
        memcpy(&acked_id, &results->rx_data[PAR_ID2_OFF], 4);
        if (ids_equal(deviceID_last4(), acked_id)) {
            // Serial.println("My own ID ACK'd");
        } else {
            // Serial.println("Another ACK'd ID!!");
            return -4;
        }
        irDataRx.id2 = acked_id;
    }

    irDataRx.valid = 1;
    return 0;
}
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
void loop() {
    switch (badgeState) {
        case BADGE_STATE_IDLE: {
            // READ AND DECODE INCOMING IR
            int ir_res = irrecv.decode(&irResults);
            if (ir_res) {
                if (irResults.decode_type == BYTES) {
                    if (parse(&irResults) == 0 && irDataRx.valid) {
                        badgeState = BADGE_STATE_MESSAGE_AVAILABLE;
                        // Serial.printlnf("irDataRx.msg:%02X, irDataRx.msg.type:%02X", *((uint8_t *)&irDataRx.msg), irDataRx.msg.type);
                        processMessage();
                    }
                }
                irrecv.resume(); // make sure to clear and re-enable IR after all tests above
                if (badgeState == BADGE_STATE_MESSAGE_AVAILABLE) {
                    break;
                }
            } else {
                // Serial.printlnf("ir_res: %d", ir_res);
            }

            // CHECK FOR BUTTON PRESSES
            // int btn = buttonPressed();
            // if (btn) {
            //     colorPick = btn;

            //     if (colorPick == 5) {
            //         // rainbow(4); // TODO: blocking, probably just remove this and wait for repeated command to display something
            //         break;
            //     }

            //     if (gameStateP1 == GAMEPLAY_STATE_IDLE || gameStateP1 == GAMEPLAY_STATE_ATTACK_ACK) {
            //         badgeState = BADGE_STATE_DIE_ROLL_INIT;
            //     }
            // }

            break;
        }
        case BADGE_STATE_SLEEP: {
            // sleepAfterDelay();
            badgeState = BADGE_STATE_WAKEUP;
            break;
        }
        case BADGE_STATE_WAKEUP: {
            badgeState = BADGE_STATE_IDLE;
            break;
        }
        case BADGE_STATE_MESSAGE_AVAILABLE: {
            badgeState = BADGE_STATE_IDLE;
            break;
        }
        case BADGE_STATE_DIE_ROLL_INIT: {
            randomNumber = random(6)+1;
            dieRoll(randomNumber, colorPick, true); // force new roll
            // Serial.printlnf("START RAND: %d", randomNumber);
            startDieRoll = millis();
            rolling = 1;
            badgeState = BADGE_STATE_DIE_ROLL;
            break;
        }
        case BADGE_STATE_DIE_ROLL: {
            if (rolling && millis() - startDieRoll < DIE_ROLL_TIMEOUT_MAX_MS) {
                rolling = dieRoll(randomNumber, colorPick);
            }
            if (!rolling) {
                badgeState = BADGE_STATE_IDLE;
                retransmits = 1;
                startRetransmit = millis() - (retransmitDelay*2); // Send immediately!
                memset(dataBuf, 0, DATA_BUF_LEN);
                if (gameStateP2 == GAMEPLAY_STATE_IDLE) {
                    gameStateP1 = GAMEPLAY_STATE_ATTACK;
                    createMessage(dataBuf, MESSAGE_TYPE_ATTACK, colorPick-1, randomNumber);
                } else if (gameStateP2 == GAMEPLAY_STATE_ATTACK) {
                    gameStateP1 = GAMEPLAY_STATE_COUNTER_ATTACK;
                    createMessage(dataBuf, MESSAGE_TYPE_COUNTER_ATTACK, colorPick-1, randomNumber, player2id, &player2msg);

                    // determine winner ahead of time
                    if (player1msg.strength > player2msg.strength) {
                        winner_id = deviceID_last4();
                    } else if (player1msg.strength < player2msg.strength) {
                        winner_id = player2id;
                    } else {
                        winner_id = GAME_IS_A_DRAW_ID;
                    }
                }
                startGamestateTimer = 0;
            }
            break;
        }
        case BADGE_STATE_SPLASH: {
            if (!playSound(irDataRx.msg.button+1+4, SOUND_STATE_PLAYING)) {
                // retransmits = 3;
                // startRetransmit = 0;
                // memcpy(&irDataRxCurrent, &irDataRx, sizeof(IRData));
                // memset(dataBuf, 0, DATA_BUF_LEN);
                // createMessage(dataBuf, MESSAGE_TYPE_ATTACK_ACK, irDataRxCurrent.msg.button, irDataRxCurrent.msg.strength);
                // gameStateP1 = GAMEPLAY_STATE_ATTACK_ACK;

                // if (gameStateP2 == GAMEPLAY_STATE_COUNTER_ATTACK) {
                //     retransmits = 1;
                //     startRetransmit = millis() - (retransmitDelay*2); // Send immediately!
                //     memset(dataBuf, 0, DATA_BUF_LEN);
                //     gameStateP1 = GAMEPLAY_STATE_SCORE_ACK;
                //     createMessage(dataBuf, MESSAGE_TYPE_RESULT, 0, 0, winner_id);
                // }

                fadeOut(1000); // blocking
                badgeState = BADGE_STATE_IDLE;
                RGB.color(0, 150, 150);
            }
            break;
        }
        case BADGE_STATE_DISPLAY_RESULT: {
            int sound = 0;
            if (gameResult == GAME_RESULT_WIN) {
                sound = 9;
            } else if (gameResult == GAME_RESULT_LOSE) {
                sound = 6;
            } else {
                sound = 5;
            }
            if (!playSound(sound, SOUND_STATE_PLAYING)) {
                fadeOut(2000); // blocking
                badgeState = BADGE_STATE_IDLE;
                resetGame();
                // Serial.printlnf("GAME FINISHED");
            }
            break;
        }
        default: {
            break;
        }
    }


    switch (gameStateP1) {
        case GAMEPLAY_STATE_IDLE: {
            break;
        }
        case GAMEPLAY_STATE_ATTACK: {

            if ((retransmits > 0) && (millis() - startRetransmit > retransmitDelay)) {

                irrecv.disableIRIn();
                irsend.sendBytes(dataBuf, MESSAGE_TYPE_ATTACK_LEN);
                irrecv.enableIRIn();

                // Serial.printlnf("ATTACK:%d", retransmits);

                // if (retransmits == 10) {
                    fadeOut(500);
                // } else {
                    retransmitDelay = 500; // * (random(4)+1);
                    startRetransmit = millis();
                // }
                // while (buttonPressed());
                // playSound(colorPick, SOUND_STATE_FINISHED); // ensure sound has stopped
                extendWakeTime();
                retransmits--;
                if (retransmits == 0) {
                    startGamestateTimer = millis();
                }
            }
            if (startGamestateTimer && (millis() - startGamestateTimer > GAME_STATE_TIMEOUT_MS)) {
                startGamestateTimer = 0;
                resetGame();
                // Serial.printlnf("ATTACK TIMEOUT");
            }
            break;
        }
        case GAMEPLAY_STATE_ATTACK_ACK: {

            if (startGamestateTimer && (millis() - startGamestateTimer > GAME_STATE_TIMEOUT_MS)) {
                startGamestateTimer = 0;
                resetGame();
                // Serial.printlnf("ATTACK_ACK TIMEOUT");
            }
            break;
        }
        case GAMEPLAY_STATE_COUNTER_ATTACK: {

            if ((retransmits > 0) && (millis() - startRetransmit > retransmitDelay)) {

                irrecv.disableIRIn();
                irsend.sendBytes(dataBuf, MESSAGE_TYPE_COUNTER_ATTACK_LEN);
                irrecv.enableIRIn();

                // Serial.printlnf("COUNTER:%d", retransmits);

                // if (retransmits == 10) {
                    fadeOut(500);
                // } else {
                    retransmitDelay = 500; // * (random(4)+1);
                    startRetransmit = millis();
                // }
                // while (buttonPressed());
                // playSound(colorPick, SOUND_STATE_FINISHED); // ensure sound has stopped
                extendWakeTime();
                retransmits--;
                if (retransmits == 0) {
                    startGamestateTimer = millis();
                }
            }
            if (startGamestateTimer && (millis() - startGamestateTimer > GAME_STATE_TIMEOUT_MS)) {
                startGamestateTimer = 0;
                resetGame();
                // Serial.printlnf("COUNTER TIMEOUT");
            }
            break;
        }
        case GAMEPLAY_STATE_COUNTER_ATTACK_ACK: {
            break;
        }
        case GAMEPLAY_STATE_RESULT: {

            if ((retransmits > 0) && (millis() - startRetransmit > retransmitDelay)) {

                irrecv.disableIRIn();
                irsend.sendBytes(dataBuf, MESSAGE_TYPE_RESULT_LEN);
                irrecv.enableIRIn();

                // Serial.printlnf("RESULT:%d", retransmits);
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

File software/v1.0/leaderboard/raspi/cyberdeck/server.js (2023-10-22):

// Run with: node server.js

const express = require('express');
const app = express();

const http = require('http');
const server = http.createServer(app);
const io = require('socket.io')(server);
const axios = require('axios');


const { SerialPort } = require('serialport');
const { ReadlineParser } = require('@serialport/parser-readline');
const serialPort = new SerialPort({ path: '/dev/ttyACM0', baudRate: 115200 }, function (err) {
    if (err) {
        return console.log('Error: ', err.message)
    }
})
const parser = serialPort.pipe(new ReadlineParser({ delimiter: '\r\n' }));

let nodeServer = 0;
let resetScreenTimer;
const hostname = 'http://192.168.1.150:3001'; // high score server has a static IP on the local network
let isIdle = true; // Prevent false re-entry from other badges while one user is in progress at the terminal

app.use(express.static('public'));

server.listen(3000, () => {
    console.log('Server is running on port 3000');
});


function isValidJSON(data) {
    if (typeof data !== "string") {
        return false;
    }
    try {
        JSON.parse(data);
        return true;
    } catch (error) {
        console.log(error);
        return false;
    }
}

function resetScreen() {
    if (nodeServer) {
        nodeServer.emit('text1', '');
        nodeServer.emit('text2', '');
        nodeServer.emit('text3', '<<< THROW BALLOON!');
        nodeServer.emit('text4', '');
        nodeServer.emit('text5', '');
        console.log('resetScreen');
        isIdle = true;
    }
}

io.on('connection', (socket) => {
    console.log('A user connected');

    nodeServer = socket;

    nodeServer.on('name-entered', async (data) => {
        console.log("nameEntered", JSON.parse(data));
        if (!isValidJSON(data)) {
            return;
        }
        let jsonData = JSON.parse(data);

        if (jsonData.cyberdeck_game_name !== undefined || jsonData.cyberdeck_game_name != "") {
            if (resetScreenTimer) {
                clearTimeout(resetScreenTimer);
                console.log('clearTimeout 1');
            }

            // CHECK IF NAME IS UNIQUE
            let nameUnique = false;
            const mydata1 = {
                id: jsonData.cyberdeck_device_id,
                nick: jsonData.cyberdeck_game_name,
            };
            await axios.post(hostname+'/user/unique', mydata1)
                .then((res) => {
                    console.log('unique response:',JSON.parse(res.data));
                    console.log('unique status:', res.status);
                    if (res.status == 200 && isValidJSON(res.data)) {
                        let result = JSON.parse(res.data);
                        if (result.res == 200) {
                            console.log('User name is not unique!');
                        } else if (result.res == 404) {
                            console.log('User name is unique!');
                            nameUnique = true;
                        }
                    }
                }).catch((err) => {
                    console.error(err);
                });

            if (!nameUnique) {
                nodeServer.emit('text4', 'NAME TAKEN, TRY AGAIN');
                if (resetScreenTimer) {
                    clearTimeout(resetScreenTimer);
                    console.log('clearTimeout 2');
                }
                resetScreenTimer = setTimeout(resetScreen, 20000);
                console.log('setTimeout 2');
                return;
            }

            console.log('Name entered:', jsonData.cyberdeck_game_name);

            nodeServer.emit('text1', 'WELCOME,');
            nodeServer.emit('text2', jsonData.cyberdeck_game_name);
            nodeServer.emit('text3', '');
            nodeServer.emit('text4', 'YOUR SCORE IS:');
            nodeServer.emit('text5', jsonData.cyberdeck_game_score);

            const mydata2 = {
                id: jsonData.cyberdeck_device_id,
                nick: jsonData.cyberdeck_game_name,
                game: "Splash",
                score: jsonData.cyberdeck_game_score,
                crc: jsonData.cyberdeck_game_crc
            };
            await axios.post(hostname+'/user/put', mydata2)
                .then((res) => {
                    if (res.status == 200 && isValidJSON(res.data)) {
                        if (res.data.res == 200) {
                            console.log('High score record created/updated!');
                        } else {
                            console.log('High score record not created/updated!');
                        }
                    }
                }).catch((err) => {
                    console.error(err);
                });

            resetScreenTimer = setTimeout(resetScreen, 10000);
            // console.log('setTimeout 4');
        }
    });
});
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

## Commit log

2023-09-04 adds badge pcb v0.1
    [particle-bamf23-badge-B_Cu.gbl, particle-bamf23-badge-B_Mask.gbs, particle-bamf23-badge-B_Paste.gbp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]
2023-10-22 adds badge pcb v1.0
    [particle-bamf23-badge-B_Cu.gbl, particle-bamf23-badge-B_Mask.gbs, particle-bamf23-badge-B_Paste.gbp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]
